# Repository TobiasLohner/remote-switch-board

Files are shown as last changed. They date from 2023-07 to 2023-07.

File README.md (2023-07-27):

# Remote Switch Board

This hardware project aims to provide a small form factor board for smart home projects.

The primary goal is to have a platform for remotely switching a garden watering system. The board can be partially populated if fewer switching outputs or other features are not required.

The board was made with KiCad 6.0.

## Main Features

* 8 solid state switches with current measurement
* SX1231 RF chip (compatible to RFM69, 433 / 868 / 915 MHz ISM frequency bands)
* STM32L0 microcontroller (optional)
* Raspberry PI header (optional)
* Frequency counter input
* Thermistor input
* Operating voltage: 12 V DC

## Microcontroller

The board has the option to either use an STM32L0 microcontroller or a Raspberry Pi to control the RF module and the switches. The microcontroller uses SPI to:
* control the switches via a shift register
* read the current feedback from a MCP3008
* communicate with the SX1231 RF chip

Further digital/analog inputs are used for:
* Thermistor input (analog input)
* Frequency counter (digital input)

Both SPI and digital input is also wired to the Raspberry PI header, such that a Raspberry Pi could be used instead of the microcontroller.

## SX1231
The SX1231 is a RF tranciever capable to be operated at license-free 433 / 868 / 915 MHz frequency bands. Tested range using 868 MHz was more than 500 meter in line-of-sight, sufficient for smart home applications.

## Electrical Characteristics
* Main operating voltage: 12 V
* Includes 5 V output to supply a Raspberry PI
* Total current limit approx. 5 A (might be more, untested)
* Switches: 12 V / 2.5 A each

# Licence
Shield: [][cc-by-sa]

This work is licensed under a
[Creative Commons Attribution-ShareAlike 4.0 International License][cc-by-sa].

[][cc-by-sa]

[cc-by-sa]: http://creativecommons.org/licenses/by-sa/4.0/
[cc-by-sa-image]: https://licensebuttons.net/l/by-sa/4.0/88x31.png
[cc-by-sa-shield]: https://img.shields.io/badge/License-CC%20BY--SA%204.0-lightgrey.svg

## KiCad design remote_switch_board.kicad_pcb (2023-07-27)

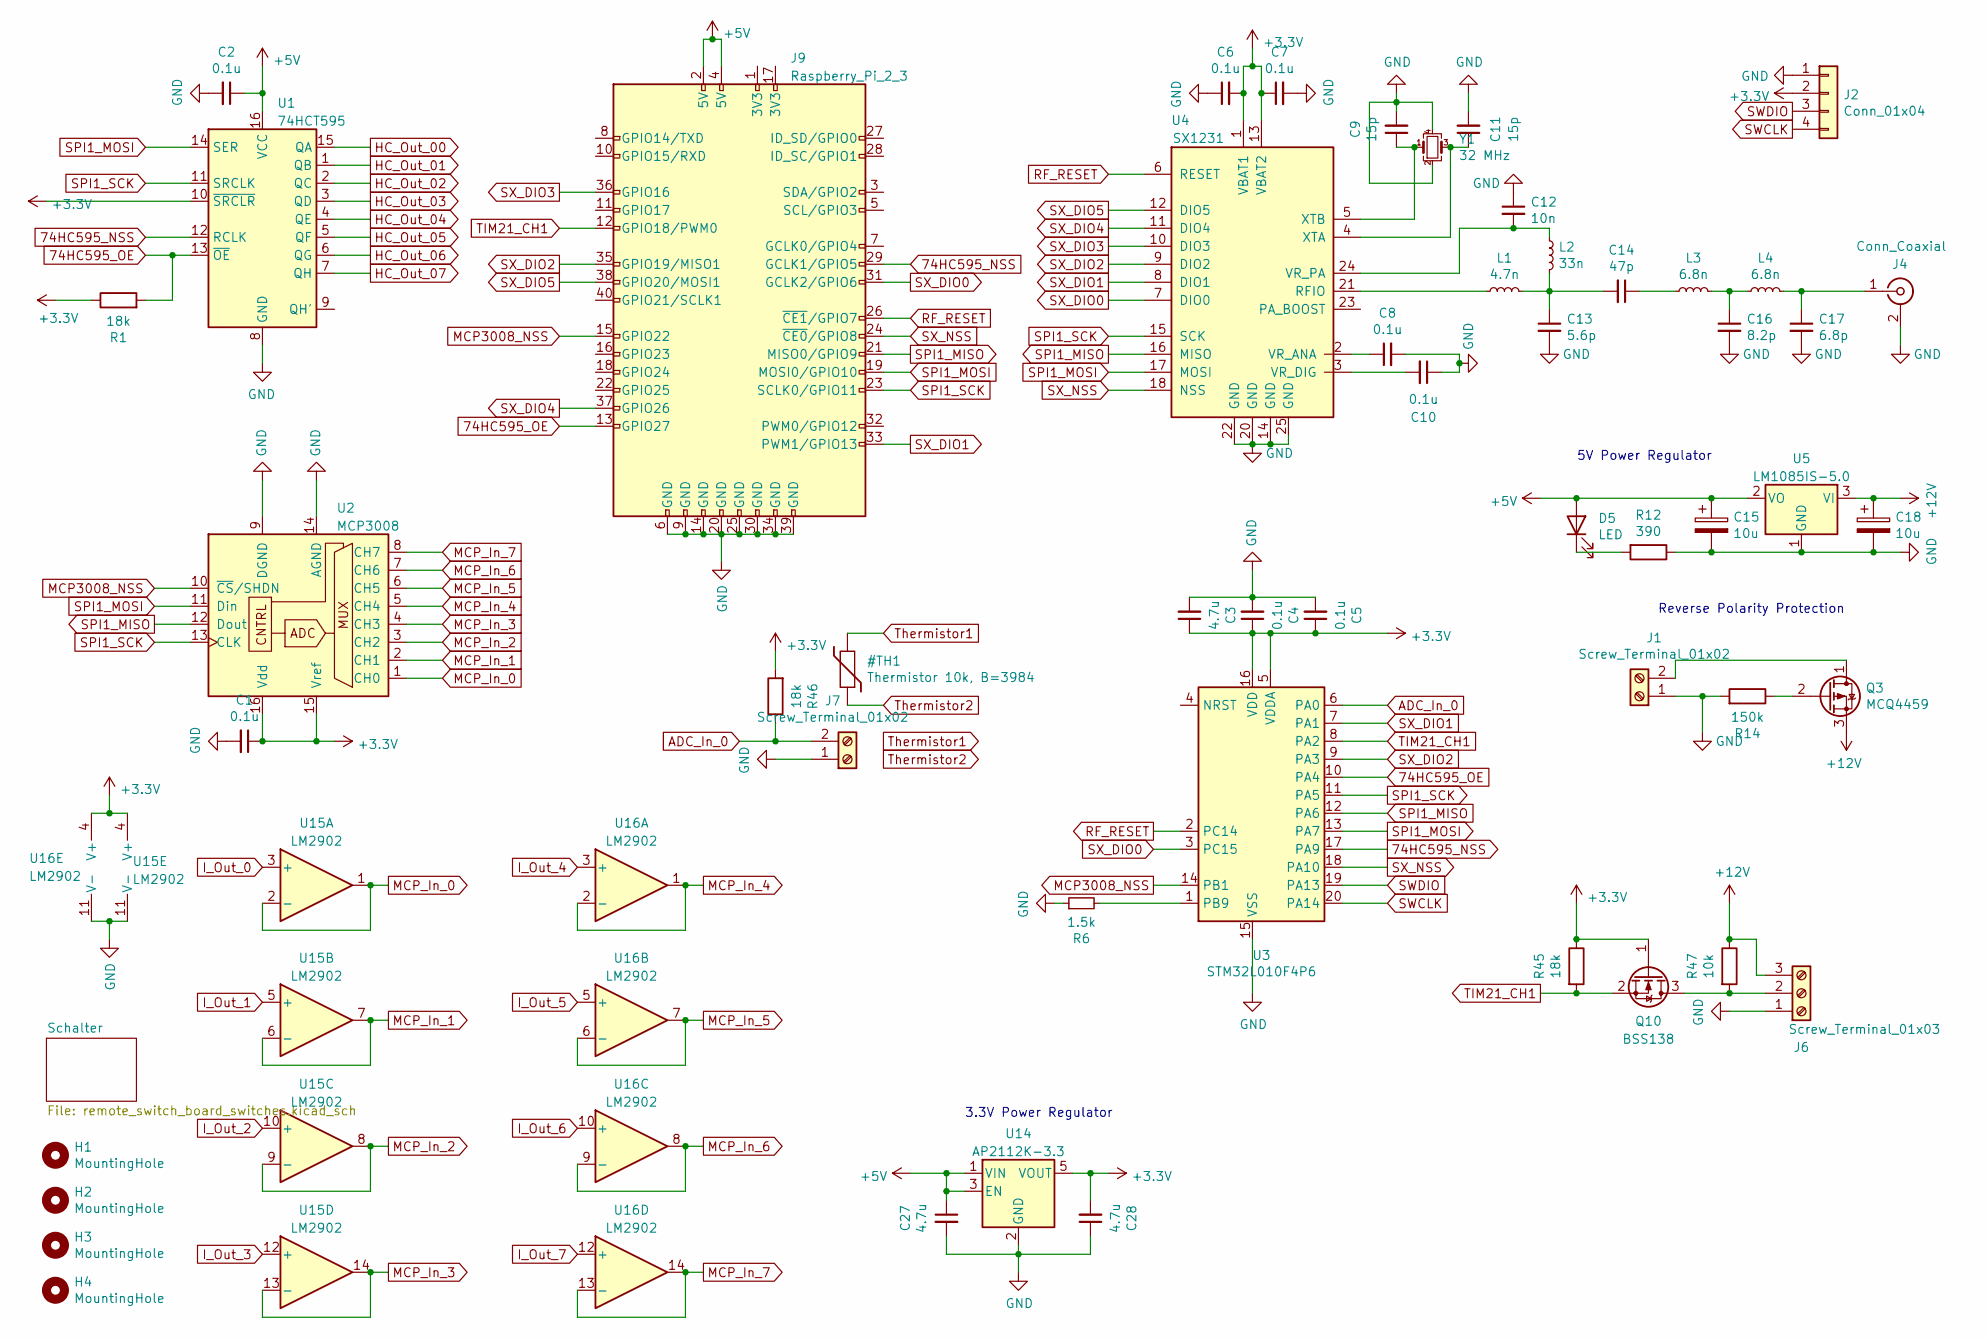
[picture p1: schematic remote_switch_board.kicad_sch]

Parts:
C1, C2, C4, C5, C6, C7, C8, C10: 0.1u; C_0603_1608Metric; Mouser-Nr. 581-0603YC104MAT4A
C3, C27, C28: 4.7u; C_0603_1608Metric; Mouser-Nr. 187-CL10B475KQ8NQNC
C9, C11: 15p; C_0603_1608Metric; Mouser-Nr. 80-C0603C150J5G
C12: 10n; C_0603_1608Metric; Mouser-Nr. 581-06035C103MAT4A
C13: 5.6p; C_0603_1608Metric; Mouser-Nr. 581-06035A5R6J
C14: 47p; C_0603_1608Metric; Mouser-Nr. 80-C0603C470J1G
C15, C18: 10u; CP_EIA-7343-31_Kemet-D; Mouser-Nr. 74-TR3D106K035C0400
C16: 8.2p; C_0603_1608Metric; Mouser-Nr. 80-C0603C829J5G
C17: 6.8p; C_0603_1608Metric; Mouser-Nr. 80-C0603C689J5G
D5: LED; LED_0805_2012Metric
H1, H2, H3, H4: MountingHole; MountingHole_2.7mm_Pad
J1, J7: Screw_Terminal_01x02; TerminalBlock_Phoenix_PT-1,5-2-3.5-H_1x02_P3.50mm_Horizontal; Mouser-Nr. 651-1984617
J2: Conn_01x04; PinHeader_1x04_P2.54mm_Vertical
J4: Conn_Coaxial; U.FL_Hirose_U.FL-R-SMT-1_Vertical; Mouser-Nr. 798-U.FL-R-SMT-110
J6: Screw_Terminal_01x03; TerminalBlock_Phoenix_PT-1,5-3-3.5-H_1x03_P3.50mm_Horizontal; Mouser-Nr. 651-1984620
J9: Raspberry_Pi_2_3; PinHeader_2x20_P2.54mm_Vertical
L1: 4.7n; L_0603_1608Metric; Mouser-Nr. 81-LQW18AN4N7C80D
L2: 33n; L_0603_1608Metric; Mouser-Nr. 81-LQW18AN33NJ00D
L3, L4: 6.8n; L_0603_1608Metric; Mouser-Nr. 81-LQW18AN6N8C00D
Q3: MCQ4459; MCQ4459_SOP-8_5.28x5.23mm_P1.27mm; Mouser-Nr. 833-MCQ4459-TP
Q10: BSS138; SOT-23; Mouser-Nr. 771-BSS138P215
R1, R45, R46: 18k; R_0603_1608Metric; Mouser-Nr. 603-RC0603FR-1018KL
R6: 1.5k; R_0603_1608Metric; Mouser-Nr. 652-CR0603FX-1501ELF
R12: 390; R_0603_1608Metric; Mouser-Nr. 603-RC0603FR-07390RL
R14: 150k; R_0603_1608Metric; Mouser-Nr. 603-RC0603FR-07150KL
R47: 10k; R_0603_1608Metric; Mouser-Nr. 603-RC0603FR-1010KL
U1: 74HCT595; TSSOP-16_4.4x5mm_P0.65mm; Mouser-Nr. 74HCT595PW,118
U2: MCP3008; SOIC-16_3.9x9.9mm_P1.27mm; Mouser-Nr. 579-MCP3008T-I/SL
U3: STM32L010F4P6; TSSOP-20_4.4x6.5mm_P0.65mm; Mouser-Nr. 511-STM32L010F4P6
U4: SX1231; QFN-24-1EP_5x5mm_P0.65mm_EP3.4x3.4mm; Mouser-Nr. 947-SX1231IMLTRT
U5: LM1085IS-5.0; TO-263-3_TabPin2; Mouser-Nr. 926-LM1085IS50NOPB
U14: AP2112K-3.3; SOT-23-5
U15, U16: LM2902; TSSOP-14_4.4x5mm_P0.65mm
Y1: 32 MHz; Crystal_SMD_2520-4Pin_2.5x2.0mm; Mouser-Nr. 344-NX2520SA32MCSW2

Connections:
74HC595_NSS: J9.29 (GCLK1/GPIO5), U1.12 (RCLK), U3.17 (PA9)
74HC595_OE: J9.13 (GPIO27), R1.2, U1.13 (~OE), U3.10 (PA4)
+3.3V: C1.1, C3.1, C4.1, C5.1, C6.2, C7.1, C28.2, J2.2, Q10.1 (G), R1.1, R45.1, R46.2, U1.10 (~SRCLR), U2.15 (Vref), U2.16 (Vdd), U3.5 (VDDA), U3.16 (VDD), U4.1 (VBAT1), U4.13 (VBAT2), U14.5 (VOUT), U15.4 (V+), U16.4 (V+); also elsewhere on the board
+5V: C2.1, C15.1, C27.1, D5.2 (A), J9.2 (5V), J9.4 (5V), U1.16 (VCC), U5.2 (VO), U14.1 (VIN), U14.3 (EN)
+12V: C18.1, J6.3, Q3.3 (S), R47.1, U5.3 (VI); also elsewhere on the board
ADC_In_0: J7.2, R46.1, U3.6 (PA0)
GND: C1.2, C2.2, C3.2, C4.2, C5.2, C6.1, C7.2, C8.2, C9.2, C10.1, C11.2, C12.1, C13.2, C15.2, C16.2, C17.2, C18.2, C27.2, C28.1, J1.1, J2.1, J4.2 (Ext), J6.1, J7.1, J9.6 (GND), J9.9 (GND), J9.14 (GND), J9.20 (GND), J9.25 (GND), J9.30 (GND), J9.34 (GND), J9.39 (GND), R6.1, R12.1, R14.2, U1.8 (GND), U2.9 (DGND), U2.14 (AGND), U3.15 (VSS), U4.14 (GND), U4.20 (GND), U4.22 (GND), U4.25 (GND), U5.1 (GND), U14.2 (GND), U15.11 (V-), U16.11 (V-), Y1.2, Y1.4; also elsewhere on the board
HC_Out_00: U1.15 (QA); also elsewhere on the board
HC_Out_01: U1.1 (QB); also elsewhere on the board
HC_Out_02: U1.2 (QC); also elsewhere on the board
HC_Out_03: U1.3 (QD); also elsewhere on the board
HC_Out_04: U1.4 (QE); also elsewhere on the board
HC_Out_05: U1.5 (QF); also elsewhere on the board
HC_Out_06: U1.6 (QG); also elsewhere on the board
HC_Out_07: U1.7 (QH); also elsewhere on the board
I_Out_0: U15.3 (+); also elsewhere on the board
I_Out_1: U15.5 (+); also elsewhere on the board
I_Out_2: U15.10 (+); also elsewhere on the board
I_Out_3: U15.12 (+); also elsewhere on the board
I_Out_4: U16.3 (+); also elsewhere on the board
I_Out_5: U16.5 (+); also elsewhere on the board
I_Out_6: U16.10 (+); also elsewhere on the board
I_Out_7: U16.12 (+); also elsewhere on the board
MCP3008_NSS: J9.15 (GPIO22), U2.10 (~CS/SHDN), U3.14 (PB1)
MCP_In_0: U2.1 (CH0), U15.1, U15.2 (-)
MCP_In_1: U2.2 (CH1), U15.6 (-), U15.7
MCP_In_2: U2.3 (CH2), U15.8, U15.9 (-)
MCP_In_3: U2.4 (CH3), U15.13 (-), U15.14
MCP_In_4: U2.5 (CH4), U16.1, U16.2 (-)
MCP_In_5: U2.6 (CH5), U16.6 (-), U16.7
MCP_In_6: U2.7 (CH6), U16.8, U16.9 (-)
MCP_In_7: U2.8 (CH7), U16.13 (-), U16.14
unnamed: C8.1, U4.2 (VR_ANA)
unnamed: C9.1, U4.5 (XTB), Y1.1
unnamed: C10.2, U4.3 (VR_DIG)
unnamed: C11.1, U4.4 (XTA), Y1.3
unnamed: C12.2, L2.1, U4.24 (VR_PA)
unnamed: C13.1, C14.2, L1.2, L2.2
unnamed: C14.1, L3.1
unnamed: C16.1, L3.2, L4.1
unnamed: C17.1, J4.1 (In), L4.2
unnamed: D5.1 (K), R12.2
unnamed: J1.2, Q3.1 (D)
unnamed: J6.2, Q10.3 (D), R47.2
unnamed: L1.1, U4.21 (RFIO)
unnamed: Q3.2 (G), R14.1
unnamed: R6.2, U3.1 (PB9)
RF_RESET: J9.26 (~CE1/GPIO7), U3.2 (PC14), U4.6 (RESET)
SPI1_MISO: J9.21 (MISO0/GPIO9), U2.12 (Dout), U3.12 (PA6), U4.16 (MISO)
SPI1_MOSI: J9.19 (MOSI0/GPIO10), U1.14 (SER), U2.11 (Din), U3.13 (PA7), U4.17 (MOSI)
SPI1_SCK: J9.23 (SCLK0/GPIO11), U1.11 (SRCLK), U2.13 (CLK), U3.11 (PA5), U4.15 (SCK)
SWCLK: J2.4, U3.20 (PA14)
SWDIO: J2.3, U3.19 (PA13)
SX_DIO0: J9.31 (GCLK2/GPIO6), U3.3 (PC15), U4.7 (DIO0)
SX_DIO1: J9.33 (PWM1/GPIO13), U3.7 (PA1), U4.8 (DIO1)
SX_DIO2: J9.35 (GPIO19/MISO1), U3.9 (PA3), U4.9 (DIO2)
SX_DIO3: J9.36 (GPIO16), U4.10 (DIO3)
SX_DIO4: J9.37 (GPIO26), U4.11 (DIO4)
SX_DIO5: J9.38 (GPIO20/MOSI1), U4.12 (DIO5)
SX_NSS: J9.24 (~CE0/GPIO8), U3.18 (PA10), U4.18 (NSS)
TIM21_CH1: J9.12 (GPIO18/PWM0), Q10.2 (S), R45.2, U3.8 (PA2)

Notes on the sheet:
3.3V Power Regulator
Reverse Polarity Protection
5V Power Regulator

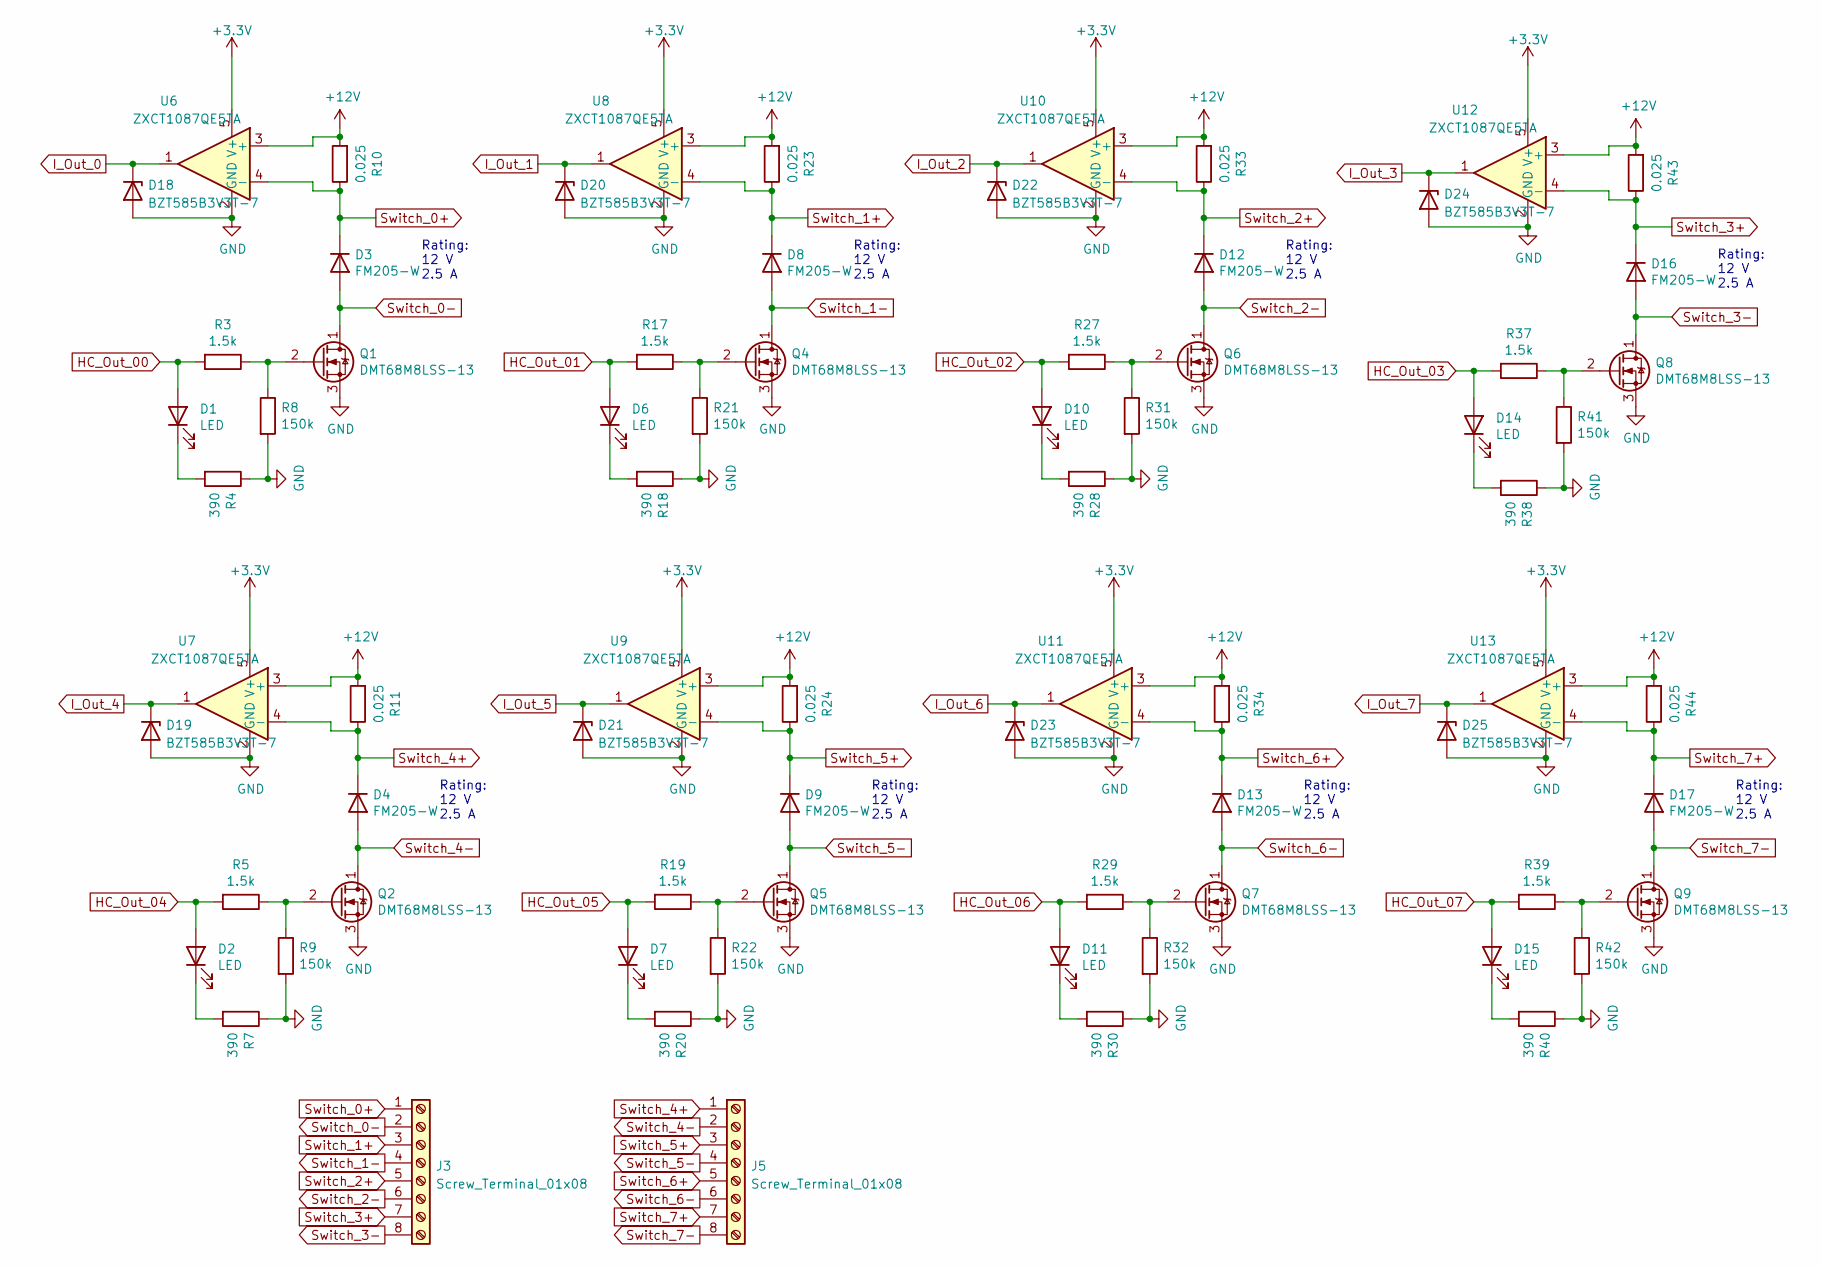
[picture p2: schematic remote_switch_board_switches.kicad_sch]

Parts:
D1, D2, D6, D7, D10, D11, D14, D15: LED; LED_0805_2012Metric
D3, D4, D8, D9, D12, D13, D16, D17: FM205-W; D_SMB; Mouser-Nr. 583-FM205
D18, D19, D20, D21, D22, D23, D24, D25: BZT585B3V3T-7; D_SOD-523; Mouser-Nr. 621-BZT585B3V3T-7
J3, J5: Screw_Terminal_01x08; TerminalBlock_Phoenix_PT-1,5-8-3.5-H_1x08_P3.50mm_Horizontal; Mouser-Nr. 651-1984675
Q1, Q2, Q4, Q5, Q6, Q7, Q8, Q9: DMT68M8LSS-13; DMT68M8LSS-13_SO-8_5.3x6.2mm_P1.27mm; Mouser-Nr. 621-DMT68M8LSS-13
R3, R5, R17, R19, R27, R29, R37, R39: 1.5k; R_0603_1608Metric; Mouser-Nr. 652-CR0603FX-1501ELF
R4, R7, R18, R20, R28, R30, R38, R40: 390; R_0603_1608Metric; Mouser-Nr. 603-RC0603FR-07390RL
R8, R9, R21, R22, R31, R32, R41, R42: 150k; R_0603_1608Metric; Mouser-Nr. 603-RC0603FR-07150KL
R10, R11, R23, R24, R33, R34, R43, R44: 0.025; R_1206_3216Metric; Mouser-Nr. 708-CSR1206FK25L0
U6, U7, U8, U9, U10, U11, U12, U13: ZXCT1087QE5TA; SOT-23-5; Mouser-Nr. 621-ZXCT1087QE5TA

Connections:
+3.3V: U6.5 (V+), U7.5 (V+), U8.5 (V+), U9.5 (V+), U10.5 (V+), U11.5 (V+), U12.5 (V+), U13.5 (V+); also elsewhere on the board
+12V: R10.2, R11.2, R23.2, R24.2, R33.2, R34.2, R43.2, R44.2, U6.3 (+), U7.3 (+), U8.3 (+), U9.3 (+), U10.3 (+), U11.3 (+), U12.3 (+), U13.3 (+); also elsewhere on the board
GND: D18.2 (A), D19.2 (A), D20.2 (A), D21.2 (A), D22.2 (A), D23.2 (A), D24.2 (A), D25.2 (A), Q1.3 (S), Q2.3 (S), Q4.3 (S), Q5.3 (S), Q6.3 (S), Q7.3 (S), Q8.3 (S), Q9.3 (S), R4.1, R7.1, R8.2, R9.2, R18.1, R20.1, R21.2, R22.2, R28.1, R30.1, R31.2, R32.2, R38.1, R40.1, R41.2, R42.2, U6.2 (GND), U7.2 (GND), U8.2 (GND), U9.2 (GND), U10.2 (GND), U11.2 (GND), U12.2 (GND), U13.2 (GND); also elsewhere on the board
HC_Out_00: D1.2 (A), R3.2; also elsewhere on the board
HC_Out_01: D6.2 (A), R17.2; also elsewhere on the board
HC_Out_02: D10.2 (A), R27.2; also elsewhere on the board
HC_Out_03: D14.2 (A), R37.2; also elsewhere on the board
HC_Out_04: D2.2 (A), R5.2; also elsewhere on the board
HC_Out_05: D7.2 (A), R19.2; also elsewhere on the board
HC_Out_06: D11.2 (A), R29.2; also elsewhere on the board
HC_Out_07: D15.2 (A), R39.2; also elsewhere on the board
I_Out_0: D18.1 (K), U6.1; also elsewhere on the board
I_Out_1: D20.1 (K), U8.1; also elsewhere on the board
I_Out_2: D22.1 (K), U10.1; also elsewhere on the board
I_Out_3: D24.1 (K), U12.1; also elsewhere on the board
I_Out_4: D19.1 (K), U7.1; also elsewhere on the board
I_Out_5: D21.1 (K), U9.1; also elsewhere on the board
I_Out_6: D23.1 (K), U11.1; also elsewhere on the board
I_Out_7: D25.1 (K), U13.1; also elsewhere on the board
unnamed: D1.1 (K), R4.2
unnamed: D2.1 (K), R7.2
unnamed: D6.1 (K), R18.2
unnamed: D7.1 (K), R20.2
unnamed: D10.1 (K), R28.2
unnamed: D11.1 (K), R30.2
unnamed: D14.1 (K), R38.2
unnamed: D15.1 (K), R40.2
unnamed: Q1.2 (G), R3.1, R8.1
unnamed: Q2.2 (G), R5.1, R9.1
unnamed: Q4.2 (G), R17.1, R21.1
unnamed: Q5.2 (G), R19.1, R22.1
unnamed: Q6.2 (G), R27.1, R31.1
unnamed: Q7.2 (G), R29.1, R32.1
unnamed: Q8.2 (G), R37.1, R41.1
unnamed: Q9.2 (G), R39.1, R42.1
Switch_0+: D3.1 (K), J3.1, R10.1, U6.4 (-)
Switch_0-: D3.2 (A), J3.2, Q1.1 (D)
Switch_1+: D8.1 (K), J3.3, R23.1, U8.4 (-)
Switch_1-: D8.2 (A), J3.4, Q4.1 (D)
Switch_2+: D12.1 (K), J3.5, R33.1, U10.4 (-)
Switch_2-: D12.2 (A), J3.6, Q6.1 (D)
Switch_3+: D16.1 (K), J3.7, R43.1, U12.4 (-)
Switch_3-: D16.2 (A), J3.8, Q8.1 (D)
Switch_4+: D4.1 (K), J5.1, R11.1, U7.4 (-)
Switch_4-: D4.2 (A), J5.2, Q2.1 (D)
Switch_5+: D9.1 (K), J5.3, R24.1, U9.4 (-)
Switch_5-: D9.2 (A), J5.4, Q5.1 (D)
Switch_6+: D13.1 (K), J5.5, R34.1, U11.4 (-)
Switch_6-: D13.2 (A), J5.6, Q7.1 (D)
Switch_7+: D17.1 (K), J5.7, R44.1, U13.4 (-)
Switch_7-: D17.2 (A), J5.8, Q9.1 (D)

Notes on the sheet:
Rating: 12 V 2.5 A

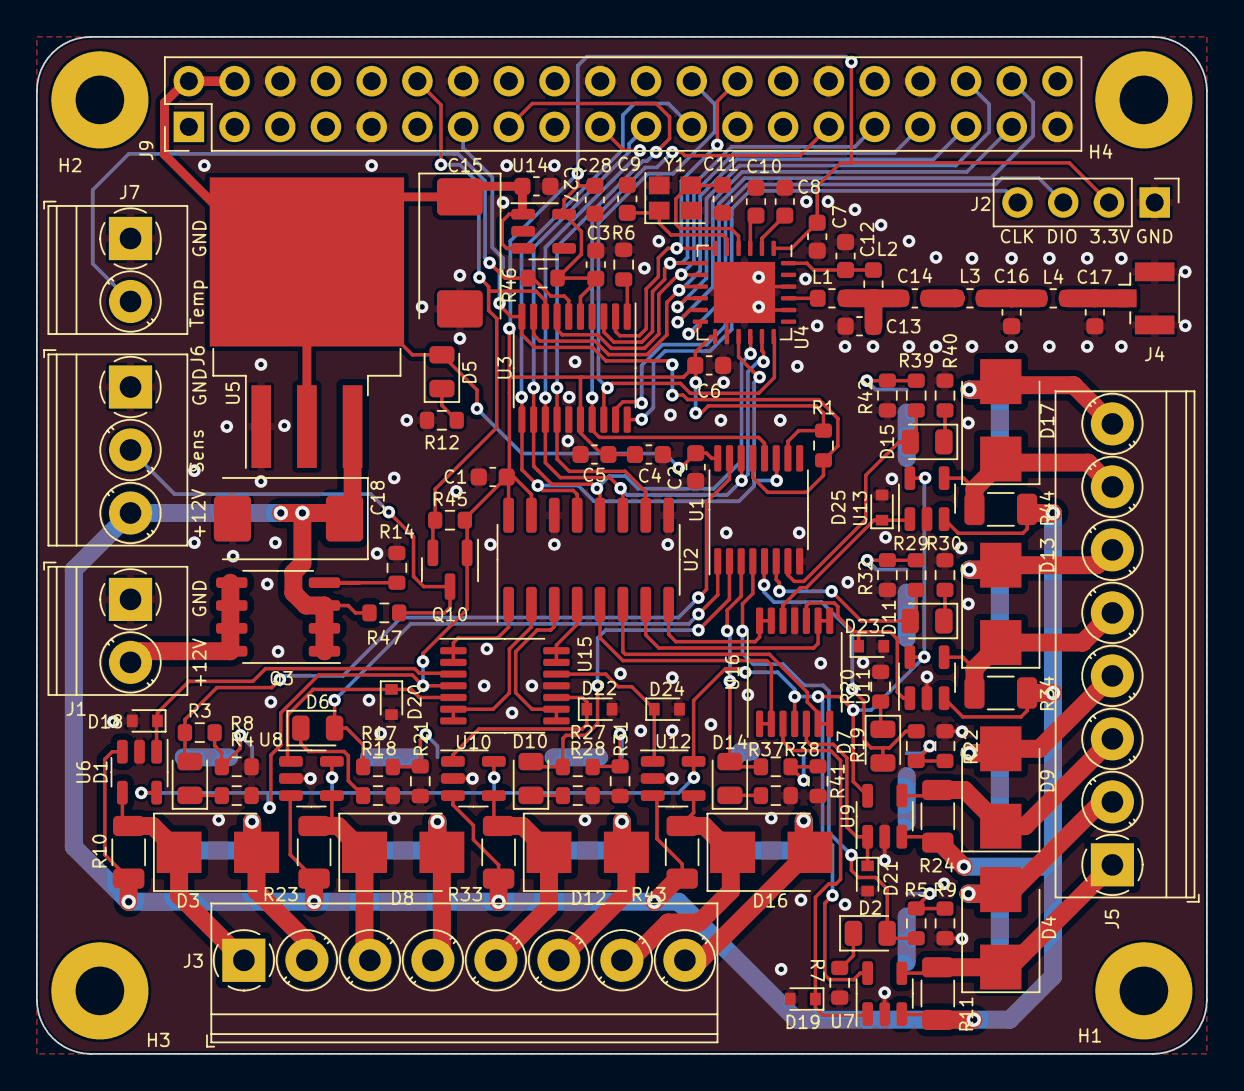
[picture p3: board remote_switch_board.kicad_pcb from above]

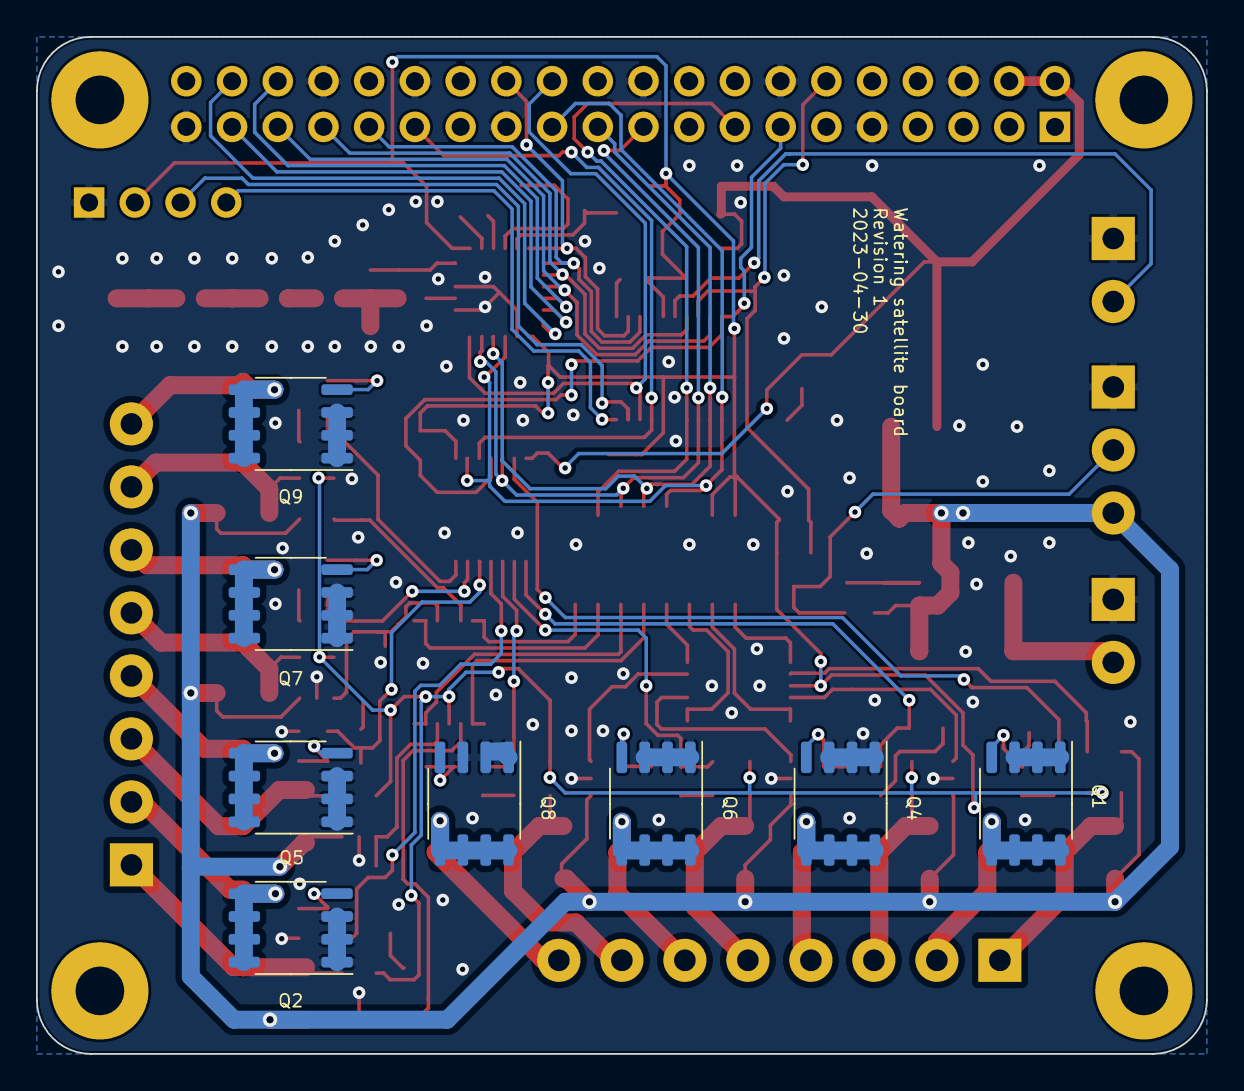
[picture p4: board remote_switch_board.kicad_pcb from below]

Board: 2 copper layers, 65.0 x 56.5 mm, 127 parts (8 on the bottom side), 93 nets.
